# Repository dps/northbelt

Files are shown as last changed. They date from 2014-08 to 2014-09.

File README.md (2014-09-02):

northbelt
=========

A belt that buzzes north

This repo contains Arduino code for a wearable compass, consisting of a belt with a number of mobile phone vibration motors mounted along its circumference.  As the wearer moves around, the motor closest to magnetic north buzzes.  According to [this WIRED article](http://archive.wired.com/wired/archive/15.04/esp.html), through the miracle of [brain plasticity](http://en.wikipedia.org/wiki/Neuroplasticity), this will give the gift of an amazing sixth sense of direction.

Hardware
========

Prototype
---------
 * [A-Star 32U4 Mini ULV](http://www.pololu.com/product/3102)
 * [LSM303D 3D Compass and Accelerometer breakout](http://www.pololu.com/product/2127)
 * [LiPoly charger](http://www.adafruit.com/products/259)
 * [Lithium Ion Polymer Battery - 3.7v 500mAh](http://www.adafruit.com/products/1578)
 * [Vibrating Mini Motor Disc](http://www.adafruit.com/products/1201) x 16
 * Motor board x16
 * 20 way ribbon cable
 * [Belt](http://amzn.com/B001FOR2CY)

Pololu A-Star
-------------

[A* Pinout](http://www.pololu.com/file/0J784/a-star-32u4-mini-pinout.pdf)

    A*  <---> LS303
    -----------------------
    5V  <---> 5V
    GND <---> GND
    2   <---> SDA
    3   <---> SCL
    4   <---> 0 degree vibe
    5   <---> 22.5
    6   <---> 45
    7   <--->
    8   <---> 90
    9   <--->
    10  <---> 135
    11  <--->
    12  <---> 180
    13  <--->
    14  <---> 225
    15  <--->
    16  <---> 270
    17  <--->
    18  <---> 315
    19  <---> 337.5

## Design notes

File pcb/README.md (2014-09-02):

This directory contains EAGLE files for the schematic and PCB layout of the motor carrier boards.

The components (x2) for the motor board can be found in the mouser saved project located at http://www.mouser.com/ProjectManager/ProjectDetail.aspx?AccessID=1ebce4eb52

The PCB is available to order as a shared project on OSHPark at https://oshpark.com/shared_projects/lNbIvA7q .  Orders at OSHPark are in multiples of 3 so order 6x to get 18 boards for 16 points of the compass.

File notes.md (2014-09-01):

Notes
-----

adafruit buzzer draws:
  - 106mA at 5V ~= 50 Ohms
  - will not activate with series 220 Ohm resistor.
  - ATmega32U4 can handle 40mA output current per digital pin => 125 Ohm @ 5V -> series 75 Ohm required.  Choose 82 for +/- 5% safety.
   - non linear current response :-(

draws 60mA with series LED

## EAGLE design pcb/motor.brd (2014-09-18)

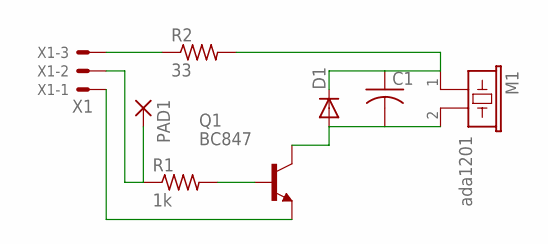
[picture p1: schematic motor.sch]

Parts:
C1: C-USC0603; C0603
D1: DIODE-DO214AC; DO214AC
M1: ada1201; B/C11L
PAD1: 1,6/0,8
Q1: BC847; SOT23
R1: 1k; R0805
R2: 33; R0805
X1: X1; 22-23-2031

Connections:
5V: R2.1, X1.3
GND: Q1.2 (E), X1.1
unnamed: PAD1.1, R1.1, X1.2
unnamed: Q1.1 (B), R1.2
unnamed: C1.2, D1.A, M1.2, Q1.3 (C)
unnamed: C1.1, D1.C, M1.1, R2.2

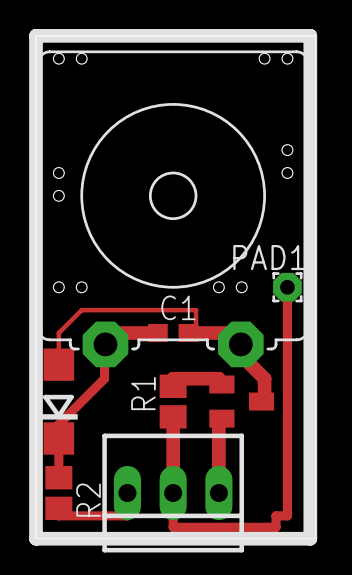
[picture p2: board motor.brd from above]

Board: 2 copper layers, 15.5 x 27.9 mm, 8 parts (0 on the bottom side), 6 nets.

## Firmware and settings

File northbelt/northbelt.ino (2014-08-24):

#include <Wire.h>
#include <LSM303.h>
#include <EEPROM.h>

#define DEBUG 1

LSM303 compass;
LSM303::vector<int16_t> running_min = {32767, 32767, 32767}, running_max = {-32768, -32768, -32768};

int CALIBRATE_LOOPS = 500;
int VIBE_BASE = 4;
int VIBE_COUNT = 16;
int SMOOTHING_DEGREES = 5;
int LED_PIN = 13;

int EEPROM_CALIBRATED_ADDR = 0;
int EEPROM_CALIBRATION_VECTOR_ADDR = 1;

float CENTER_WEDGE = (360 / VIBE_COUNT) / 2;

int currentVibePin = VIBE_BASE;

int vibrateCycles = 0;
float heading = 0.0;
float lastVibratedHeading = 180.0;

void makeCalibrateStartVibePattern() {
  for (int i = VIBE_BASE; i < VIBE_BASE + VIBE_COUNT; i++) {
    digitalWrite(i, HIGH);
    delay(250);
    digitalWrite(i, LOW);
  }
}

void makeCalibrateDoneVibePattern() {
  for (int j = 0; j < 2; j++) {
    for (int i = VIBE_BASE; i < VIBE_BASE + VIBE_COUNT; i++) {
      digitalWrite(i, HIGH);
    }
    delay(250);
    for (int i = VIBE_BASE; i < VIBE_BASE + VIBE_COUNT; i++) {
      digitalWrite(i, LOW);
    }
  }
}

void dumpCalibrationData() {
    Serial.print("calibration data: ");
    Serial.print(running_min.x);
    Serial.print(" ");
    Serial.print(running_min.y);
    Serial.print(" ");
    Serial.print(running_min.z);
    Serial.print(", ");
    Serial.print(running_max.x);
    Serial.print(" ");
    Serial.print(running_max.y);
    Serial.print(" ");
    Serial.print(running_max.z);
    Serial.println();
}

void calibrate() {

  makeCalibrateStartVibePattern();
  
  int led = HIGH;
  
  for(int i = 0; i < CALIBRATE_LOOPS; i++) {
    compass.read();
    
    running_min.x = min(running_min.x, compass.m.x);
    running_min.y = min(running_min.y, compass.m.y);
    running_min.z = min(running_min.z, compass.m.z);
  
    running_max.x = max(running_max.x, compass.m.x);
    running_max.y = max(running_max.y, compass.m.y);
    running_max.z = max(running_max.z, compass.m.z);
    
    digitalWrite(LED_PIN, led);
    if (led == HIGH) {
      led = LOW;
    } else {
      led = HIGH;
    }
    
    delay(50);
  }

  if (DEBUG) {
    dumpCalibrationData();
  }
  
  makeCalibrateDoneVibePattern();
}

bool isCalibrated() {
  // Unwritten addresses have the value 255.
  // We write 128 when marking uncalibrated so we can
  // distinguish the two states.
  // We write 0 when calibration data is stored.
  int val = EEPROM.read(EEPROM_CALIBRATED_ADDR);
  if (DEBUG) {
    Serial.print("calibrated? ");
    Serial.println(val);
  }
  return val < 128;
}

int16_t readInt16FromEEPROM(int addr) {
  int16_t ret;
  byte* p = (byte*)(void*)&ret;
  for (int i = 0; i < sizeof(int16_t); i++) {
    *p++ = EEPROM.read(addr++);
  }
  return ret;
}

void writeInt16ToEEPROM(int addr, int16_t val) {
  byte* p = (byte*)(void*)&val;
  for (int i = 0; i < sizeof(int16_t); i++) {
    EEPROM.write(addr++, *p++);
  }
}

void readCalibrationData() {
  int addr = EEPROM_CALIBRATION_VECTOR_ADDR;
  running_min.x = readInt16FromEEPROM(addr);
  addr += sizeof(int16_t);
  running_min.y = readInt16FromEEPROM(addr);
  addr += sizeof(int16_t);
  running_min.z = readInt16FromEEPROM(addr);
  addr += sizeof(int16_t);
  
  running_max.x = readInt16FromEEPROM(addr);
  addr += sizeof(int16_t);
  running_max.y = readInt16FromEEPROM(addr);
  addr += sizeof(int16_t);
  running_max.z = readInt16FromEEPROM(addr);
  addr += sizeof(int16_t);
  
  if (DEBUG) {
    Serial.print("READ from EEPROM ");
    dumpCalibrationData();
  }
}

void writeCalibrationData() {
  int addr = EEPROM_CALIBRATION_VECTOR_ADDR;
  writeInt16ToEEPROM(addr, running_min.x);
  addr += sizeof(int16_t);
  writeInt16ToEEPROM(addr, running_min.y);
  addr += sizeof(int16_t);
  writeInt16ToEEPROM(addr, running_min.z);
  addr += sizeof(int16_t);
  writeInt16ToEEPROM(addr, running_max.x);
  addr += sizeof(int16_t);
  writeInt16ToEEPROM(addr, running_max.y);
  addr += sizeof(int16_t);
  writeInt16ToEEPROM(addr, running_max.z);
  addr += sizeof(int16_t);

  EEPROM.write(EEPROM_CALIBRATED_ADDR, 0);
}

void setup() {
  Serial.begin(9600);
  Wire.begin();
  compass.init();
  compass.enableDefault();
  
  for (int i = 0; i < VIBE_COUNT; i++) {
    pinMode(VIBE_BASE + i, OUTPUT);
  }
  
  pinMode(LED_PIN, OUTPUT);

  if (DEBUG) {
    digitalWrite(LED_PIN, HIGH);
    delay(1500);
    Serial.println("DEBUG");
    digitalWrite(LED_PIN, LOW);
  }
  
  if (!isCalibrated()) {
    calibrate();
    writeCalibrationData();
  } else {
    readCalibrationData();
  }

  compass.m_min = running_min;
  compass.m_max = running_max;
}

void maybeVibrateHeading() {
  int motor = 0;
  int wedge = 0;
  if (abs(lastVibratedHeading - heading) > SMOOTHING_DEGREES) {
    lastVibratedHeading = heading;

    wedge = (((int)(heading + CENTER_WEDGE)) % 360);
    wedge = wedge / (360 / VIBE_COUNT);
    motor = wedge + VIBE_BASE;

    if (DEBUG) {
      Serial.print("vibe ");
      Serial.print(wedge);
      Serial.print(" ");
      Serial.print(motor);
      Serial.println();
    }
    digitalWrite(currentVibePin, LOW);
    digitalWrite(motor, HIGH);
    currentVibePin = motor;
    vibrateCycles = 8;
  }
}

void vibrateClock() {
  if (vibrateCycles > 0) {
    vibrateCycles--;
    if (vibrateCycles == 0) {
      digitalWrite(currentVibePin, LOW);
    }
  }
}

void loop() {
  compass.read();
  
  /*
   compass.heading((LSM303::vector<int>){0, 0, 1});
     => use the +Z axis as a reference (points directly through the PCB from
     silkscreened side to populated side).
  */
  heading = compass.heading((LSM303::vector<int>){0, 0, 1});
  maybeVibrateHeading();
  vibrateClock();
  
  if (DEBUG) {
    Serial.print("heading ");
    Serial.println(heading);
  }

  delay(100);
}

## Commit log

2014-08-19 Add lsm303-arduino as a submodule
2014-08-19 Initial Arduino sketch
2014-08-23 first prototype
2014-08-24 Use correct axis for orientation in belt. Factor out DEBUG code. Add fancy calibration UI.
    [northbelt.ino]
2014-08-24 Read and write calibration data to EEPROM on the AVR
2014-09-01 Added PCB design for motor boards.
    [motor.brd, motor.sch]
2014-09-02 Added an extra pad for the control signal on motor board.
    [motor.brd, motor.sch]
2014-09-18 Add sewable drill holes to the motor board
    [motor.brd]
